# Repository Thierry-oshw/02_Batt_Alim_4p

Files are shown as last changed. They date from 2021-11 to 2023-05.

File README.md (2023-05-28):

# 02_Batt_Alim_4p

Module Batt_alim avec 4 pins.

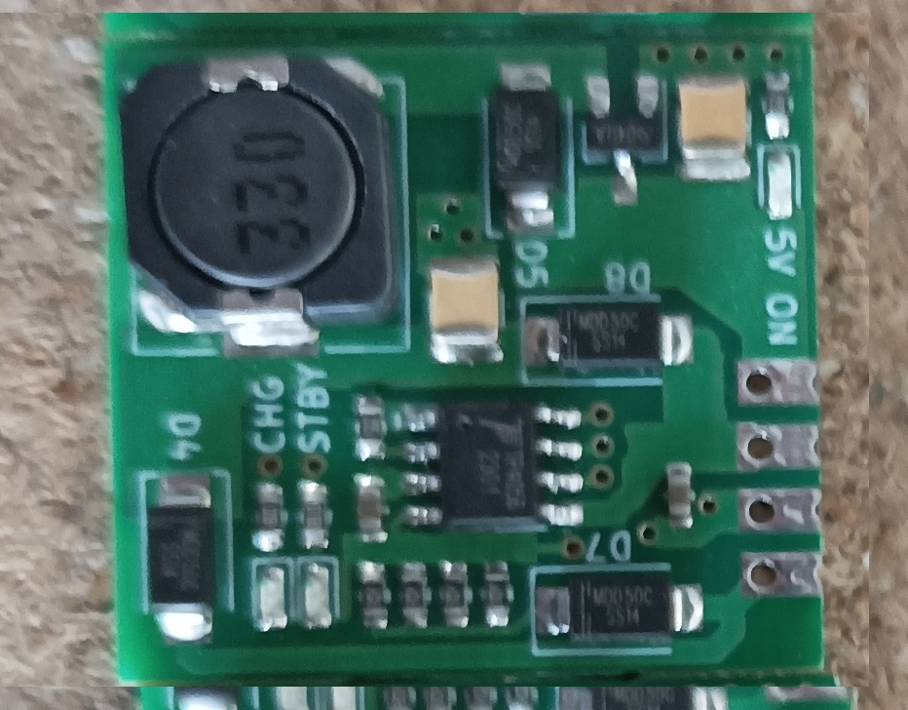
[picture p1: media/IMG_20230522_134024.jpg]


Le module Batt_Alim permet de gérer la charge d'une batterie Lipo constituée d'une seule cellule (4.2V) à partir d'une source de type 5V USB.
Il permet aussi de récupérer cette tension batterie variable et de reconstituer un 5V constant grâce à un DCDC.

[La licence est celle du CERN Open Hardware Licence version 2; CERN-OHL-P ; permissive.](https://github.com/Thierry-oshw/02_Batt_Alim_4p/blob/main/LICENSE.txt)

## Schéma et fonctionnement

Ci-joint le schéma de la version de 2021_02_23 // Here schematic of version 2021_02_23:
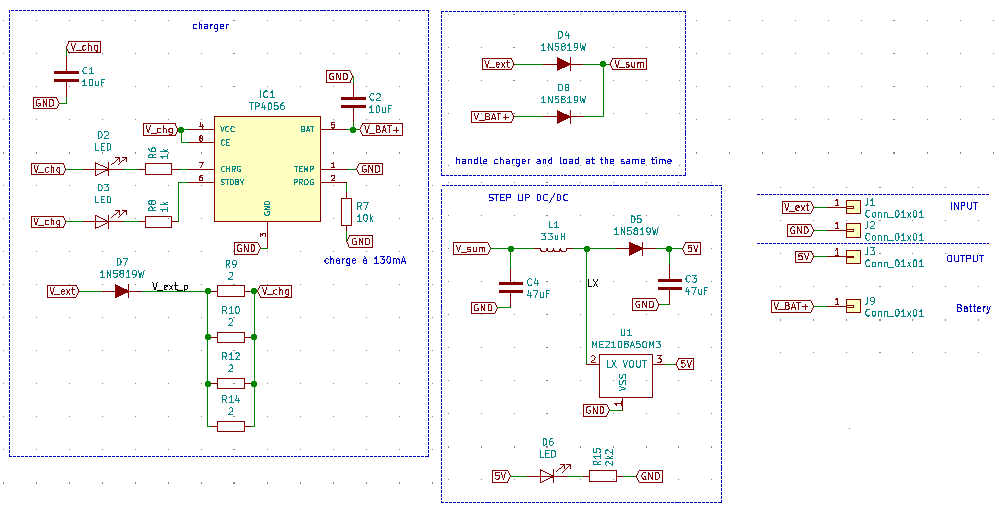
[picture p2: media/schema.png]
02_Batt_Alim schéma du module


Le module fonctionne de la façon suivante:
Il faut l'alimenter avec une tension 5V +-5% (typiquement celle de l'USB classique) sur la pin Vext. (Ne pas oublier GND bien sûr).

Il faut brancher la batterie Lipo sur V_bat+ et GND. La batterie Lipo doit être constituée d'une seule cellule, qui doit être chargée à 4.2V, présente une tension de 3.7V typique, et dont la tension de mise en protection est de 3V. La résistance R7 de 10kOhms permet de régler la puce TP4056 sur un courant de charge de 130mA. La batterie Lipo doit donc avoir une capacité d'au moins 2*130mAh, soit 260mAh au minimum. Plus d'information sur [www.tp4056.com](www.tp4056.com).

La sortie 5V est une tension issue du DCDC.

La LED D6 indique la présence de 5V à la sortie du DCDC, avec "5V ON" comme étiquette.

Les LEDs D2 et D3 indiquent respectivement la charge et le mode standby du TP4056. Les étiquettes sont "CHG" et "STBY".

## Fonctionnalités
- Petit (28x25.2 mm)
- Faible coût (2 couches avec composants d'un seul côté)
- Connecteur avec pas de 2.54 mm + empreinte crénelée pour connexion carte à carte

## Outils utilisés

- [Kicad V6](https://www.kicad.org/)

## Fabrication du circuit

Ce circuit a été testé de fond en comble sur de nombreux projets

## Contributeurs

- Thierry Orlandi ([Hardware Freelance](https://www.linkedin.com/in/thierry-orlandi))
- Yohann Belair ([R&D Freelance](https://github.com/ciborg971))

## Licence
[CERN Open Hardware Licence Version 2](https://github.com/Thierry-oshw/02_Batt_Alim_4p/blob/main/LICENSE.txt)

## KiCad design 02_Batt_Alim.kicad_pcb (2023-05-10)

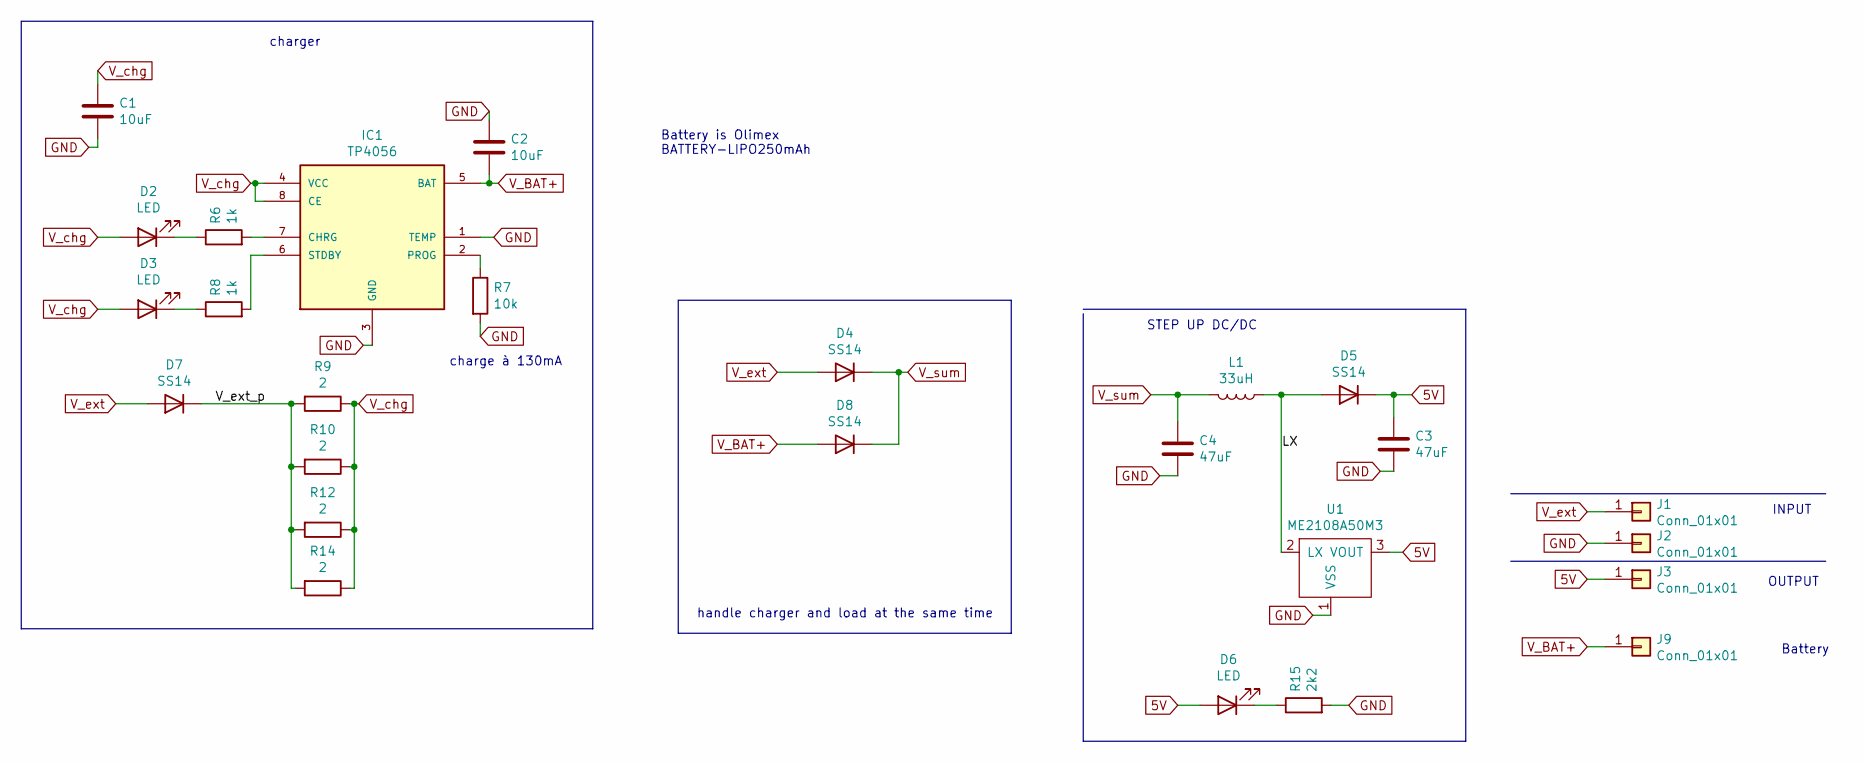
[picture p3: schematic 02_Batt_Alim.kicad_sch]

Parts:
C1, C2: 10uF; C_0603_1608Metric; LCSC C19702
C3, C4: 47uF; C_1210_3225Metric; LCSC C77101
D2, D3, D6: LED; D_0603_1608Metric; LCSC C2286
D4, D5, D7, D8: SS14; D_SMA; LCSC C2480
IC1: TP4056; SOP-8; LCSC C16581
J1, J2, J3, J9: Conn_01x01; Castellated_conn
L1: 33uH; L_10.4x10.4_H4.8; LCSC C9936
R6, R8: 1k; R_0603_1608Metric; LCSC C21190
R7: 10k; R_0603_1608Metric; LCSC C22765
R9, R10, R12, R14: 2; R_0603_1608Metric; LCSC C22977
R15: 2k2; R_0603_1608Metric; LCSC C4190
U1: ME2108A50M3; SOT-23_Handsoldering; LCSC C14839

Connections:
5V: C3.1, D5.1 (K), D6.2 (A), J3.1, U1.3 (VOUT)
/LX: D5.2 (A), L1.1, U1.2 (LX)
/V_ext_p: D7.1 (K), R9.2, R10.2, R12.2, R14.2
GND: C1.2, C2.1, C3.2, C4.2, IC1.1 (TEMP), IC1.3 (GND), J2.1, R7.2, R15.2, U1.1 (VSS)
unnamed: D2.1 (K), R6.1
unnamed: D3.1 (K), R8.1
unnamed: D6.1 (K), R15.1
unnamed: IC1.2 (PROG), R7.1
unnamed: IC1.6 (STDBY), R8.2
unnamed: IC1.7 (CHRG), R6.2
V_BAT+: C2.2, D8.2 (A), IC1.5 (BAT), J9.1
V_chg: C1.1, D2.2 (A), D3.2 (A), IC1.4 (VCC), IC1.8 (CE), R9.1, R10.1, R12.1, R14.1
V_ext: D4.2 (A), D7.2 (A), J1.1
V_sum: C4.1, D4.1 (K), D8.1 (K), L1.2

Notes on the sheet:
handle charger and load at the same time
STEP UP DC/DC
INPUT
charger
Battery
Battery is Olimex BATTERY-LIPO250mAh
OUTPUT
charge à 130mA

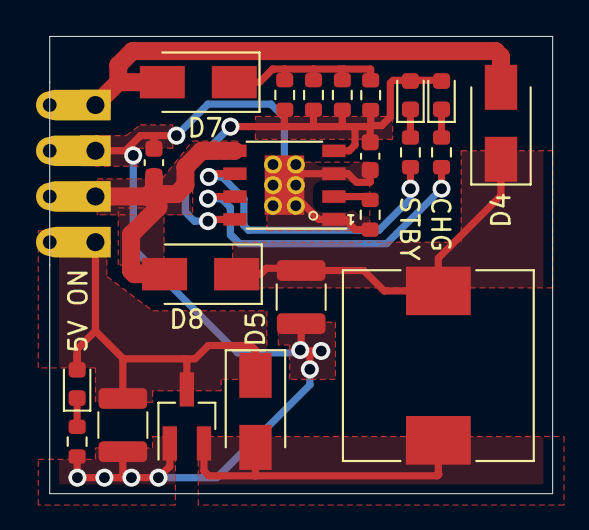
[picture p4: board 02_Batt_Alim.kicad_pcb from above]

Board: 2 copper layers, 27.9 x 25.4 mm, 26 parts (0 on the bottom side), 14 nets.

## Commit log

2021-09-14 initialisation
    from 02_Batt_alim project at tag 2021_03_03_fab
    [02_Batt_Alim.kicad_pcb, 02_Batt_Alim.sch]
2021-09-14 maj librairies
    split librairies avec maj chemin, symboles et empreintes + pcb
    [02_Batt_Alim.kicad_pcb]
2021-11-28 maj readme
    ajout schema.png pour plus de clarté
2023-05-10 maj kicad v6
    [02_Batt_Alim.kicad_sch, 02_Batt_Alim.sch]
2023-05-10 maj schéma avec champ lcsc
    [02_Batt_Alim.kicad_sch]
2023-05-10 pcb passage kicad v6
    [02_Batt_Alim.kicad_pcb]
2023-05-10 maj schema retouche placement et routage fabrication
    [02_Batt_Alim-B_Cu.gbl, 02_Batt_Alim-B_Fab.gbr, 02_Batt_Alim-B_Mask.gbs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]
2023-05-10 bom + placement
